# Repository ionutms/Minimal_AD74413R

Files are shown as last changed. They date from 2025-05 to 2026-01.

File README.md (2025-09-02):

# Minimal_AD74413R

## Overview

This repository contains a minimal KiCad design project for the Analog Devices AD74413R, a quad-channel, software-configurable input and output device. The project includes schematic designs and PCB layout files for implementing this versatile analog I/O device.

## Disclaimer

> [!NOTE]
> This project is provided "as is" and without any warranty, express or implied. For more details, please see the [LICENSE](LICENSE) file.

## About the AD74413R

The AD74413R from Analog Devices is a quad-channel, software-configurable input/output solution for building and process control applications. It integrates a 16-bit, sigma-delta (Σ-Δ) analog-to-digital converter (ADC) and four 13-bit digital-to-analog converters (DACs).

Key features include:

- **Software-Configurable Channels:** Each of the four channels can be independently configured as:
  - Analog Input (Voltage or Current)
  - Analog Output (Voltage or Current)
  - Digital Input
  - Resistance Temperature Detector (RTD) and Thermocouple measurements
- **Multiple Operating Modes:**
  - Voltage Output: 0 V to 10 V
  - Current Output: 0 mA to 24 mA
  - Voltage Input: ±10 V
  - Current Input: 0 mA to 24 mA (externally powered and loop-powered)
  - Digital Input: Logic and loop-powered
- **High Accuracy:** Includes a high-accuracy 2.5V internal reference.
- **Robustness and Diagnostics:** Features on-chip diagnostics like open-circuit and short-circuit detection.
- **HART Compatibility:** Compatible with HART (Highway Addressable Remote Transducer) protocol.
- **Communication:** Uses a Serial Peripheral Interface (SPI) for configuration and data transfer.
- **Operating Temperature Range:** -40°C to +105°C.

## Project Structure

```
minimal_ad74413r/
├── minimal_ad74413r.kicad_sch       # Main schematic file
├── minimal_ad74413r.kicad_pcb       # PCB layout file
├── minimal_ad74413r.kicad_pro       # Project configuration file
├── fp-lib-table                     # Footprint library table
├── sym-lib-table                    # Symbol library table
├── Front End Channel 1.kicad_sch    # Channel-specific schematic
├── project_jobs_set.kicad_jobset    # Project job settings
├── ibom.config.ini                  # Interactive BOM configuration
├── docs/                            # Documentation files
│   ├── pictures/                    # Images and photos
│   ├── schematics/                  # Schematic PDF exports
│   └── 3d_models/                   # 3D model files
└── KiCAD_Symbols_Generator/         # Submodule for symbol generation from CSV data
```

## Project Features

This design provides a minimal implementation of the AD74413R with the following features:

- **Power Supply:**
  - AVDD: +24V
  - AVSS: -24V
  - IOVDD: +3.3V
  - AVDD_REG and DVDD_REG: +1.8V (internally regulated)
- **Channel Configuration:**
  - Basic protection circuits for each of the four I/O channels.
  - Support for all operating modes of the AD74413R.
- **Bill of Materials (BOM):**
  - Interactive HTML BOM (`ibom.html`) for easy component identification and sourcing.
- **Libraries:**
  - Comprehensive symbol and footprint libraries integrated as a submodule.
- **3D Model:**
  - Includes a 3D model of the board for better visualization.

## Getting Started

### Prerequisites

- [KiCad EDA](https://www.kicad.org/) version 9.0 or later installed on your system
- Git (for cloning the repository and submodule management)

### Opening the Project

1. **Clone the repository** (including submodules):
   ```bash
   git clone --recursive https://github.com/ionutms/Minimal_AD74413R.git
   ```
   
   If you've already cloned the repository without submodules, initialize them with:
   ```bash
   git submodule init
   git submodule update
   ```

2. **Open the project in KiCad**:
   - Launch KiCad
   - Click "Open Existing Project"
   - Navigate to the cloned repository folder
   - Select the `minimal_ad74413r.kicad_pro` file

3. **Explore the design**:
   - Open the schematic editor to view the circuit design
   - Open the PCB editor to view the board layout
   - Review the symbol and footprint libraries used in the design

### Project Files

- **Main schematic**: `minimal_ad74413r.kicad_sch` - Contains the primary circuit design with the AD74413R and support components
- **Channel schematic**: `Front End Channel 1.kicad_sch` - Detailed implementation of one channel with protection and filtering
- **PCB layout**: `minimal_ad74413r.kicad_pcb` - Physical board design file with proper component placement
- **Project configuration**: `minimal_ad74413r.kicad_pro` - KiCad project settings

## Dependencies

This project has the following dependencies:

### 1. KiCAD Symbols Generator

This repository uses [KiCAD_Symbols_Generator](https://github.com/ionutms/KiCAD_Symbols_Generator) as a submodule for custom symbol generation.

To initialize the submodule after cloning this repository:

```bash
git submodule update --init --recursive
```

### 2. 3D Models

This project requires the [3D_Models_Vault](https://github.com/ionutms/3D_Models_Vault) repository for 3D models.

#### Setup for KiCAD 9:

1. Clone the 3D models repository:
   ```bash
   git clone https://github.com/ionutms/3D_Models_Vault.git
   ```

2. In KiCAD 9, add an environment variable:
   - Variable name: `KICAD9_3D_MODELS_VAULT`
   - Variable value: Full path to where you cloned the 3D_Models_Vault repository

## Usage

After setting up the dependencies, open the project in KiCad 9 to access all features including the 3D models.

## Symbol Generator Submodule

This project includes the KiCAD_Symbols_Generator as a submodule, which provides tools for generating KiCad symbols from CSV data files. For more information on using this tool, see the [KiCAD_Symbols_Generator documentation](minimal_ad74413r/KiCAD_Symbols_Generator/README.md).

## Documentation

The `docs` folder contains:
- Schematic PDF exports
- Images and photos of the design
- 3D model files (GLB and WRL formats)

## Visuals

The following images showcase the PCB design from different perspectives:

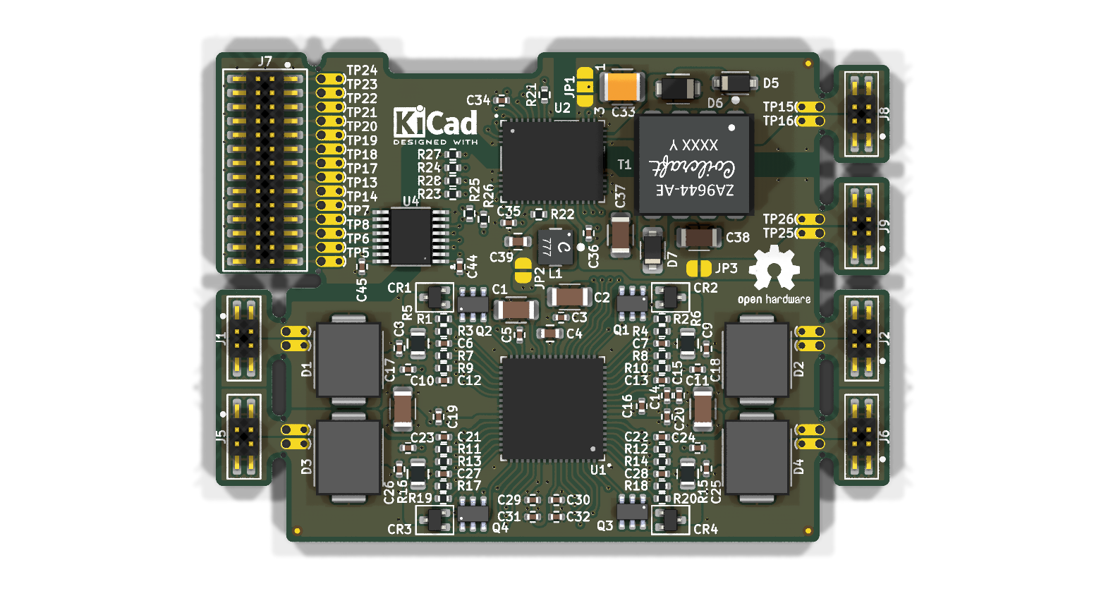
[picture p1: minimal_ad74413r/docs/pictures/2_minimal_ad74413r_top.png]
Top View

*Top View of the PCB*

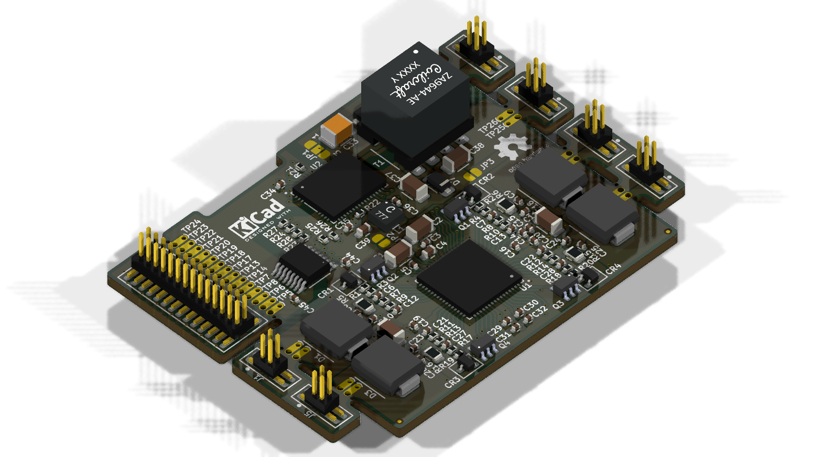
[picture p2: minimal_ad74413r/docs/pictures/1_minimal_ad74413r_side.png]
Side View

*Side View of the PCB*

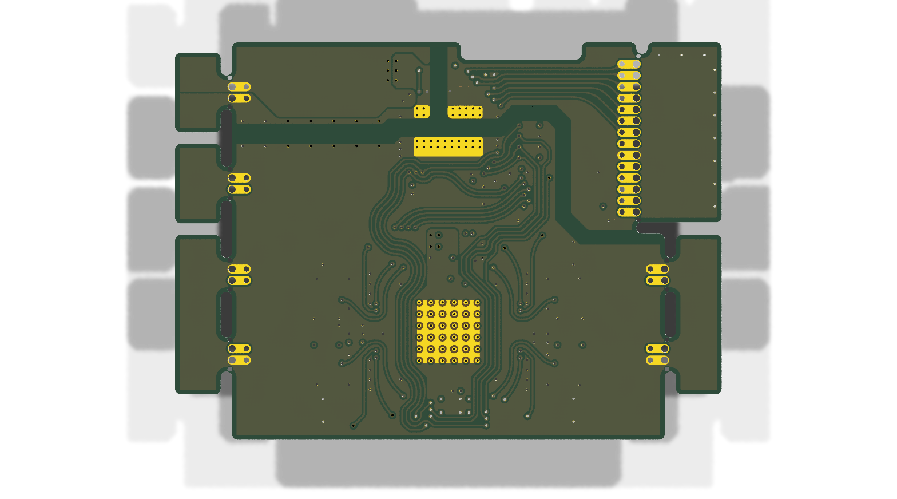
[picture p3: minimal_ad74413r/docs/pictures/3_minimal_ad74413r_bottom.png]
Bottom View

*Bottom View of the PCB*

## License

This project is licensed under the MIT License - see the [LICENSE](LICENSE) file for details.

## References

- [AD74413R Datasheet](https://www.analog.com/media/en/technical-documentation/data-sheets/ad74413r.pdf)
- [KiCad EDA](https://www.kicad.org/)

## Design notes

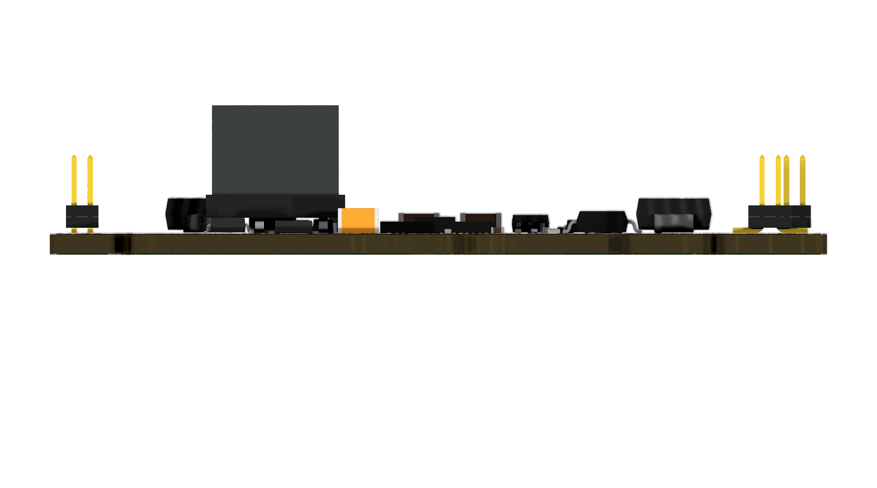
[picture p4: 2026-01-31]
minimal_ad74413r/docs/pictures/7_minimal_ad74413r_back.png

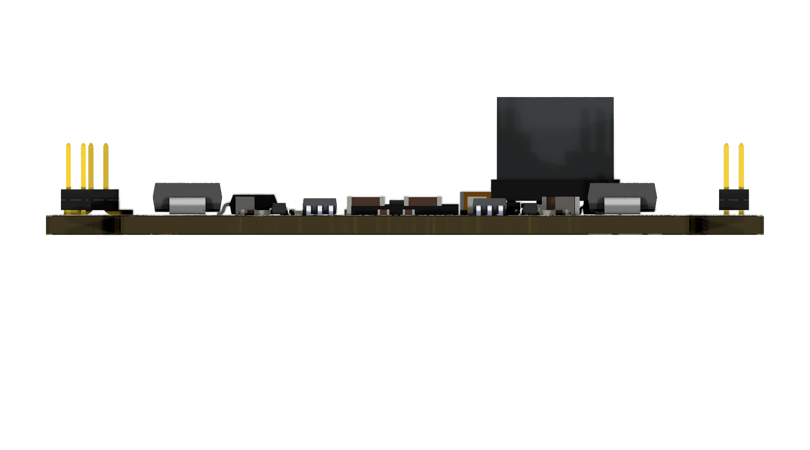
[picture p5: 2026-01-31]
minimal_ad74413r/docs/pictures/6_minimal_ad74413r_front.png

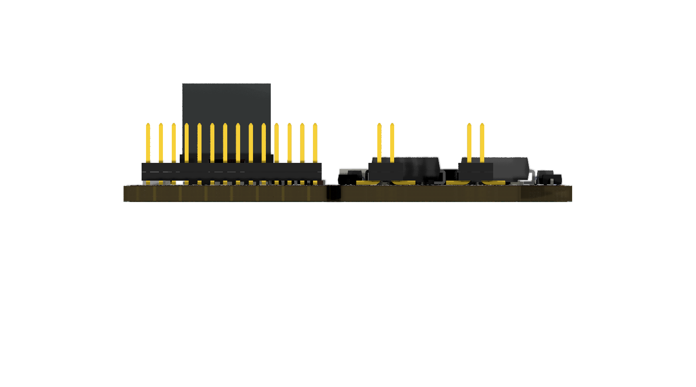
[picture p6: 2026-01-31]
minimal_ad74413r/docs/pictures/4_minimal_ad74413r_left.png

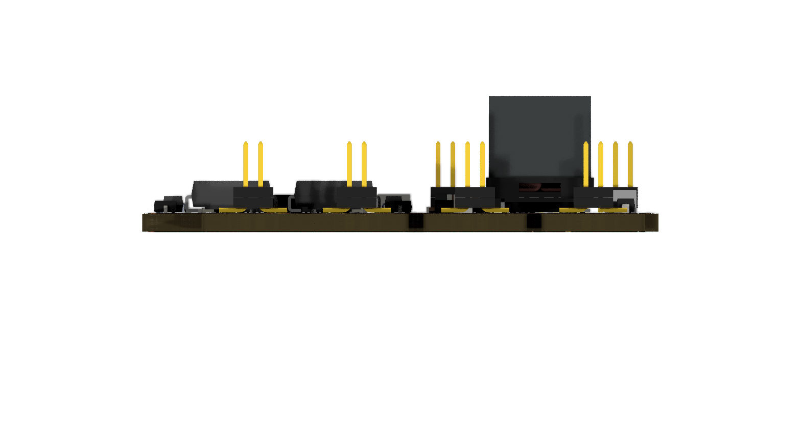
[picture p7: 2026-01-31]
minimal_ad74413r/docs/pictures/5_minimal_ad74413r_right.png

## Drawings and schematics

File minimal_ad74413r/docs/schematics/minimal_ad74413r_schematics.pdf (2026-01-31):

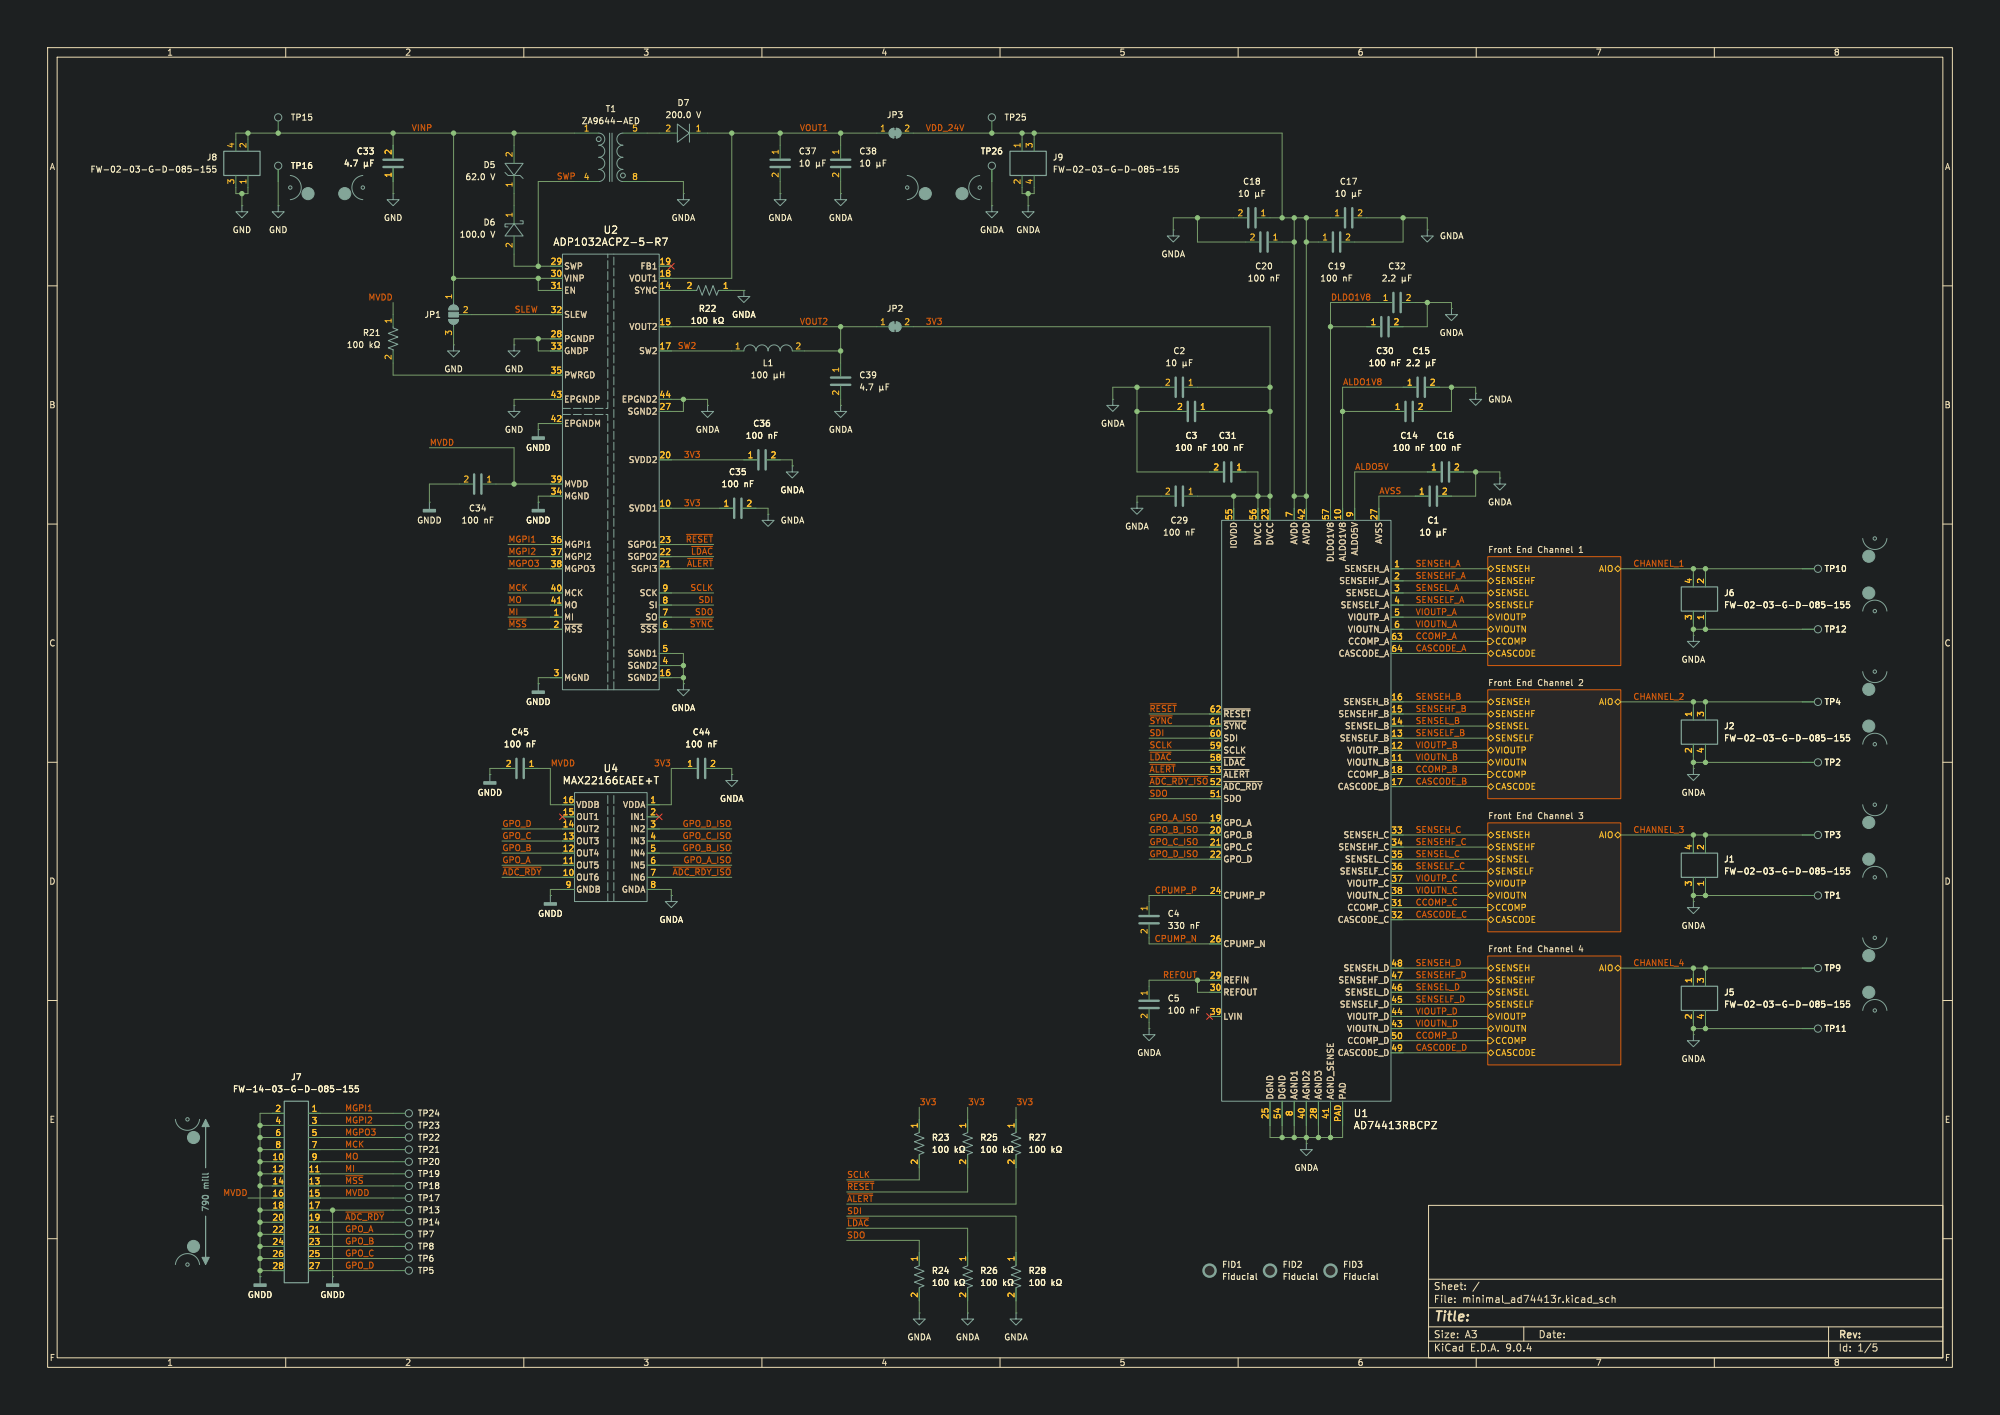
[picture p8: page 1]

SWP 29 VINP 30 EN 31 SLEW 32 PGNDP 28 GNDP 33 PWRGD 35 EPGNDP 43 EPGNDM 42 MVDD 39 MGND 34 MGPI1 36 MGPI2 37 MGPO3 38 MCK 40 MO 41 MI 1 MGND 3

SWP

9 AVSS27 SENSEH_A 1 SENSEHF_A 2 SENSEL_A 3 SENSELF_A 4 VIOUTP_A 5 VIOUTN_A 6 CCOMP_A 63 CASCODE_A64 SENSEH_B 16 SENSEHF_B 15 SENSEL_B 14 SENSELF_B 13 VIOUTP_B 12 VIOUTN_B 11 CCOMP_B 18 CASCODE_B 17 SENSEH_C 33 SENSEHF_C 34 SENSEL_C 35 SENSELF_C 36 VIOUTP_C 37 VIOUTN_C 38 CCOMP_C 31 CASCODE_C32 SENSEH_D 48 SENSEHF_D 47 SENSEL_D 46 SENSELF_D 45 VIOUTP_D 44 VIOUTN_D 43 CCOMP_D 50 CASCODE_D49 ~{RESET} 62 ~{SYNC} 61 ~{LDAC} 58 ~{ALERT} 53 ~{ADC_RDY} 52 DGND 25 DGND 54 AGND1

IN6 7 GNDA 8 VDDB 16 OUT1 15 OUT2 14 OUT3 13 OUT4 12 OUT5 11 OUT6 10 GNDB 9 GNDD

Id: 1/5 Title: File: minimal_ad74413r.kicad_sch Sheet: /

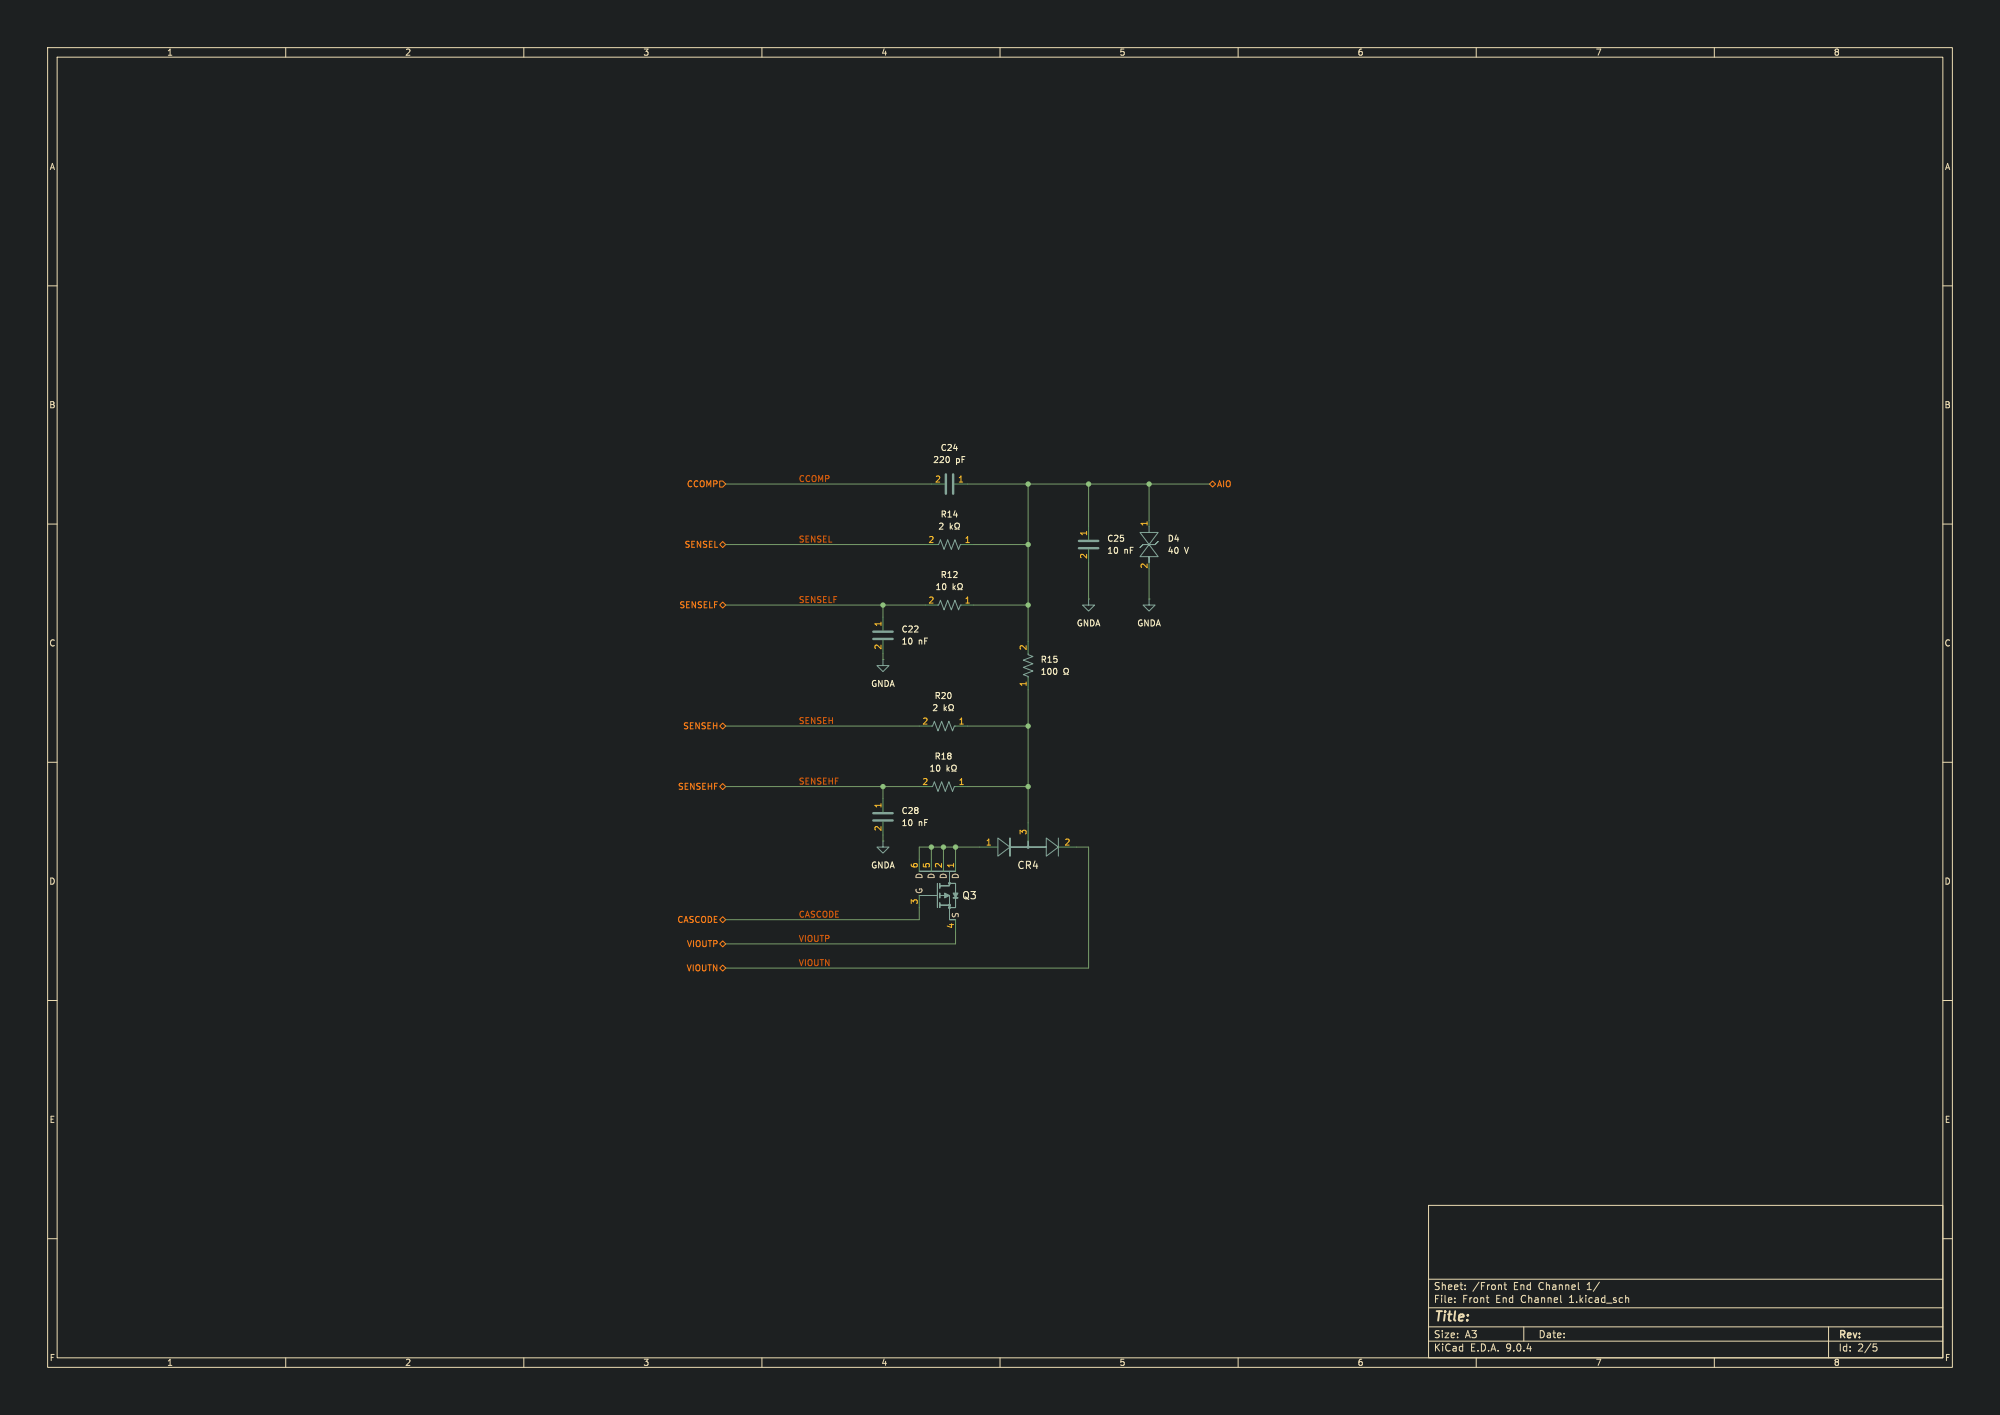
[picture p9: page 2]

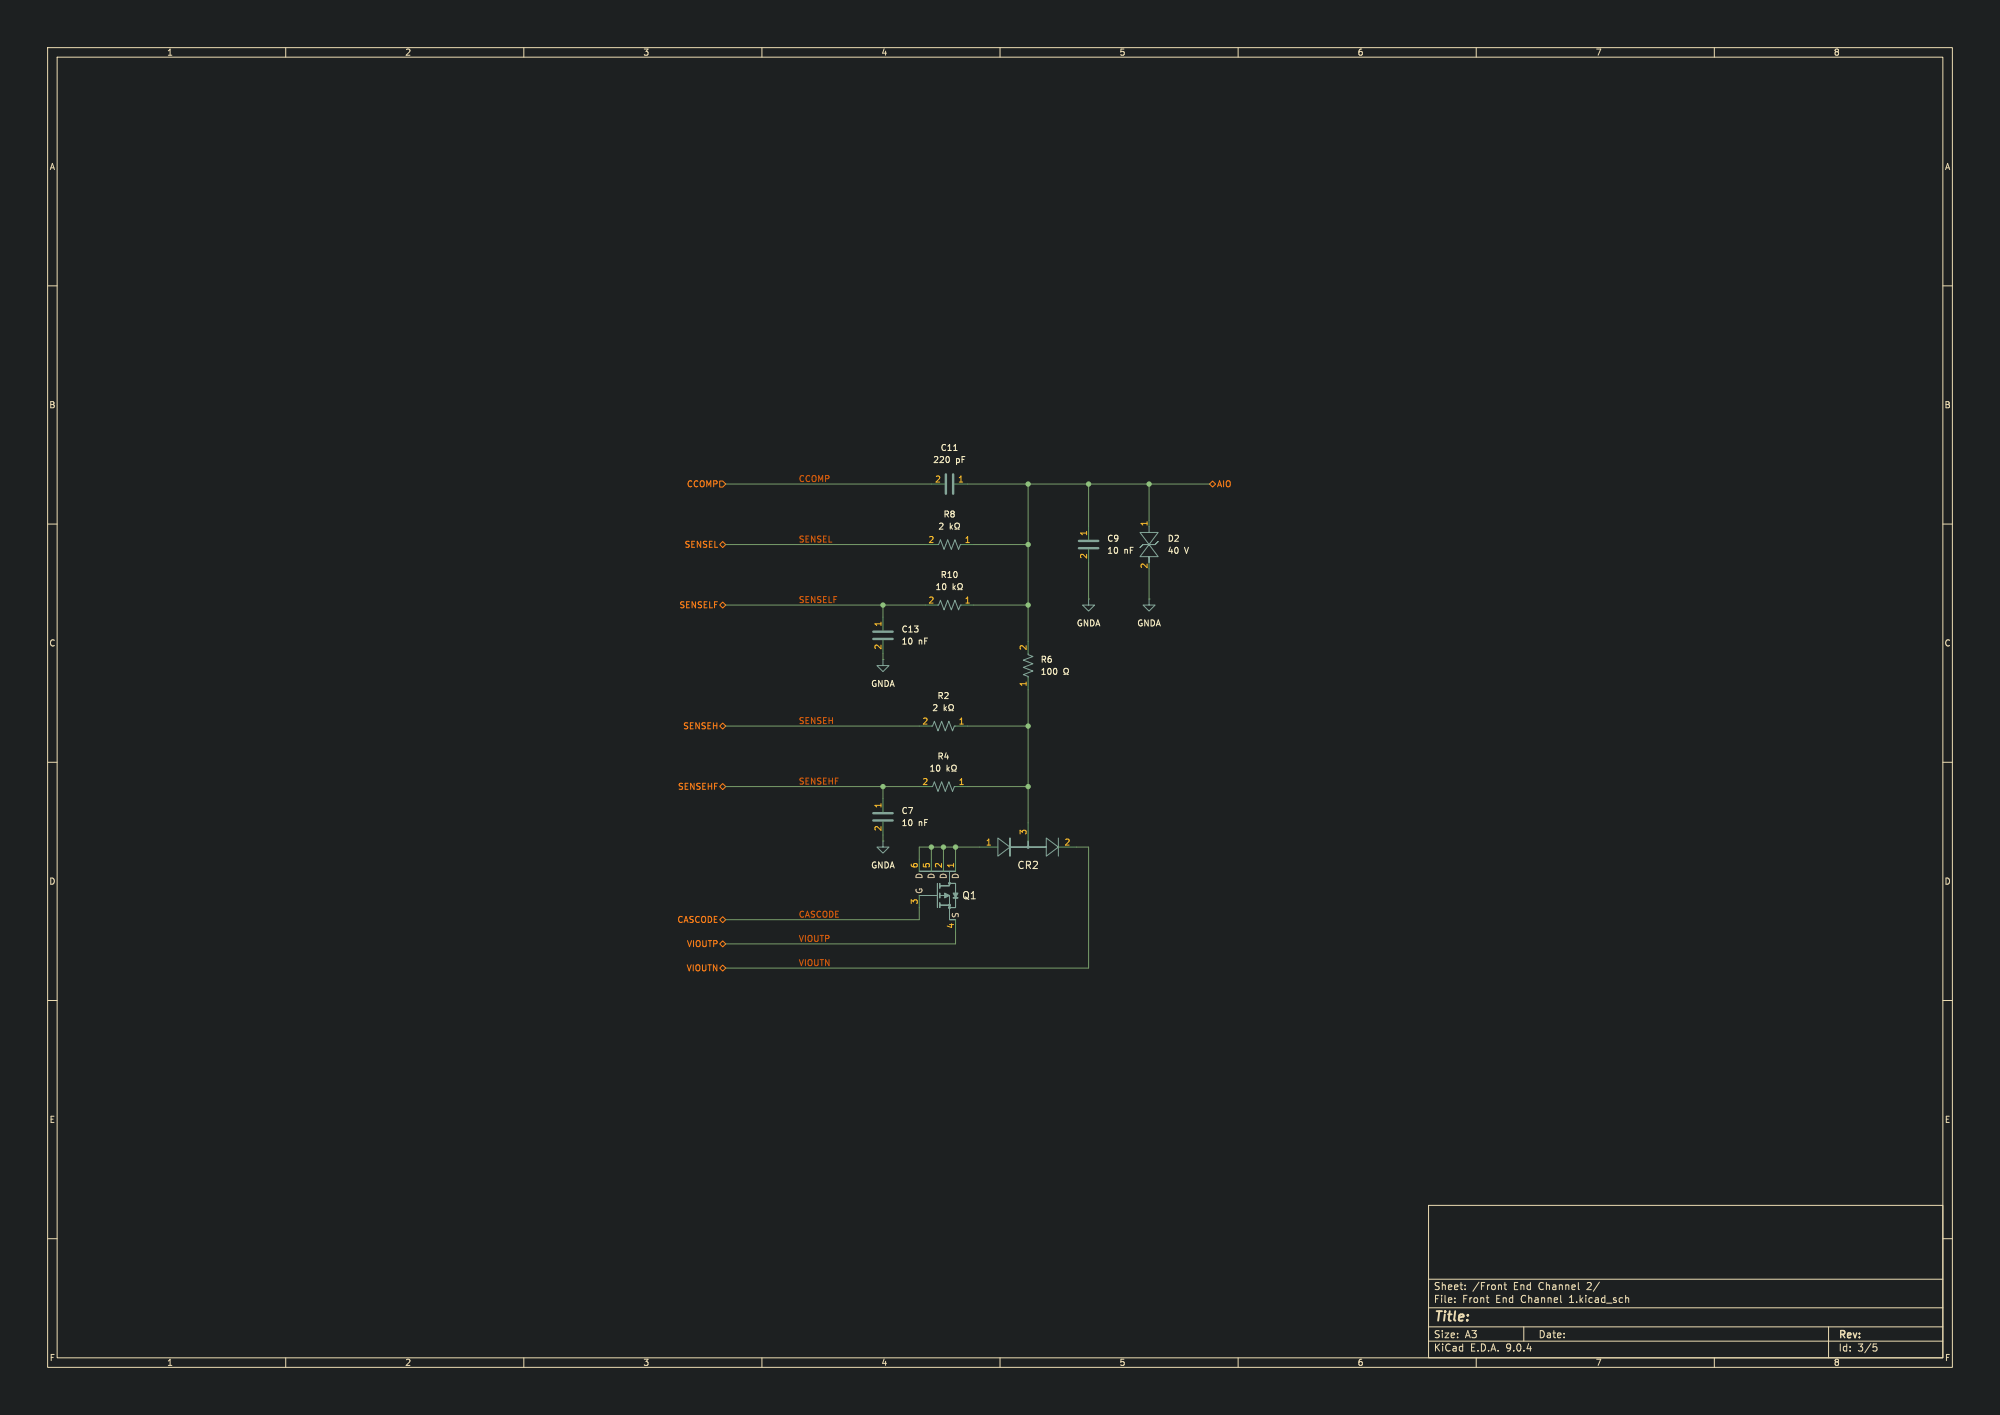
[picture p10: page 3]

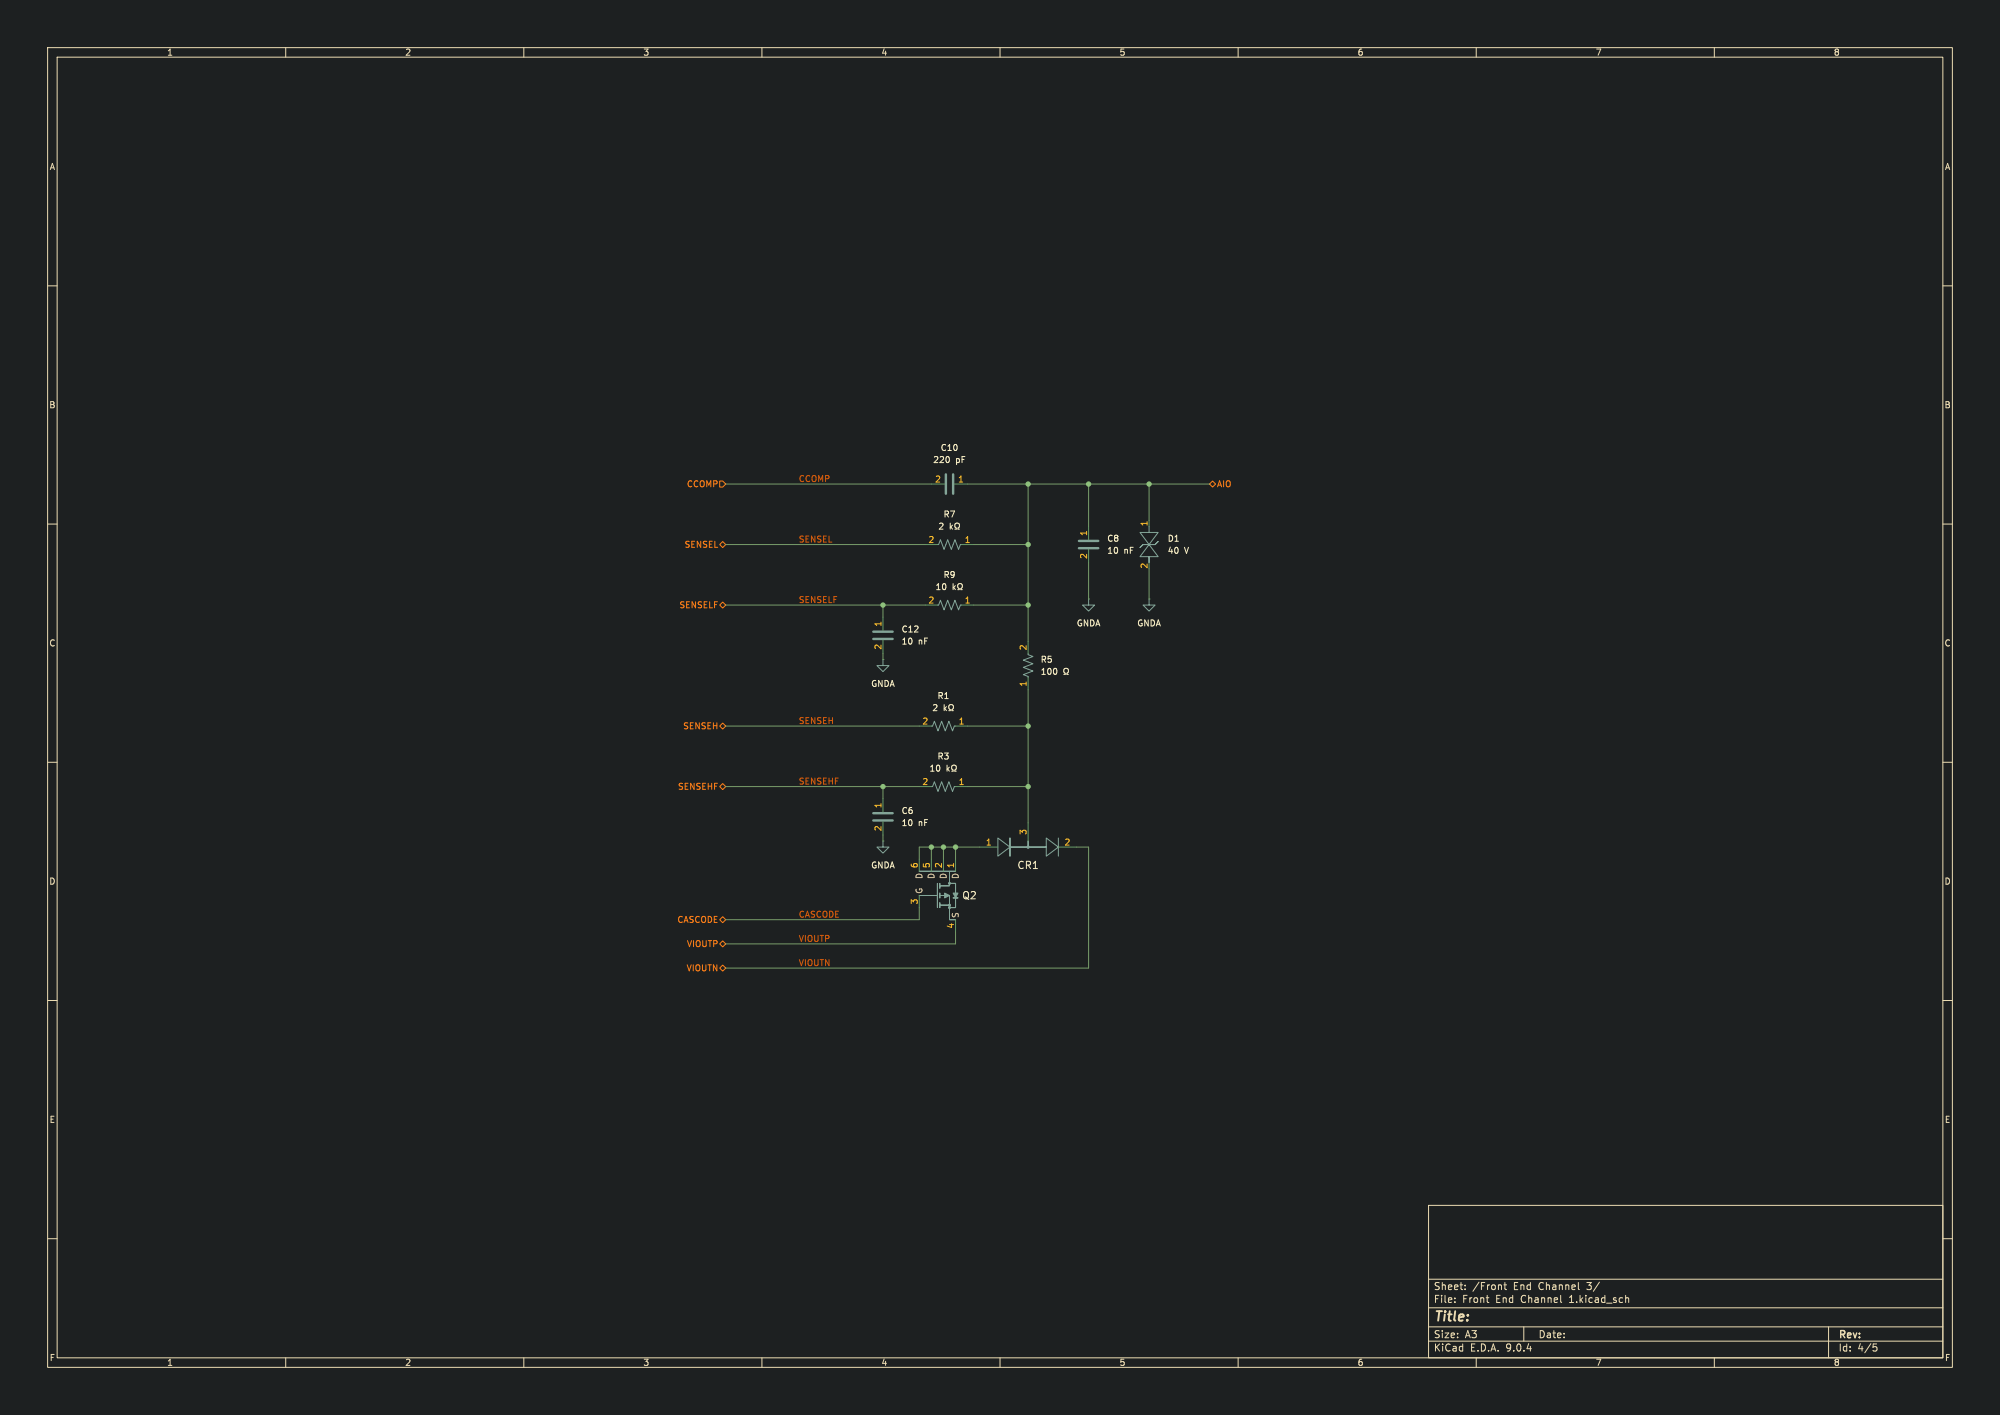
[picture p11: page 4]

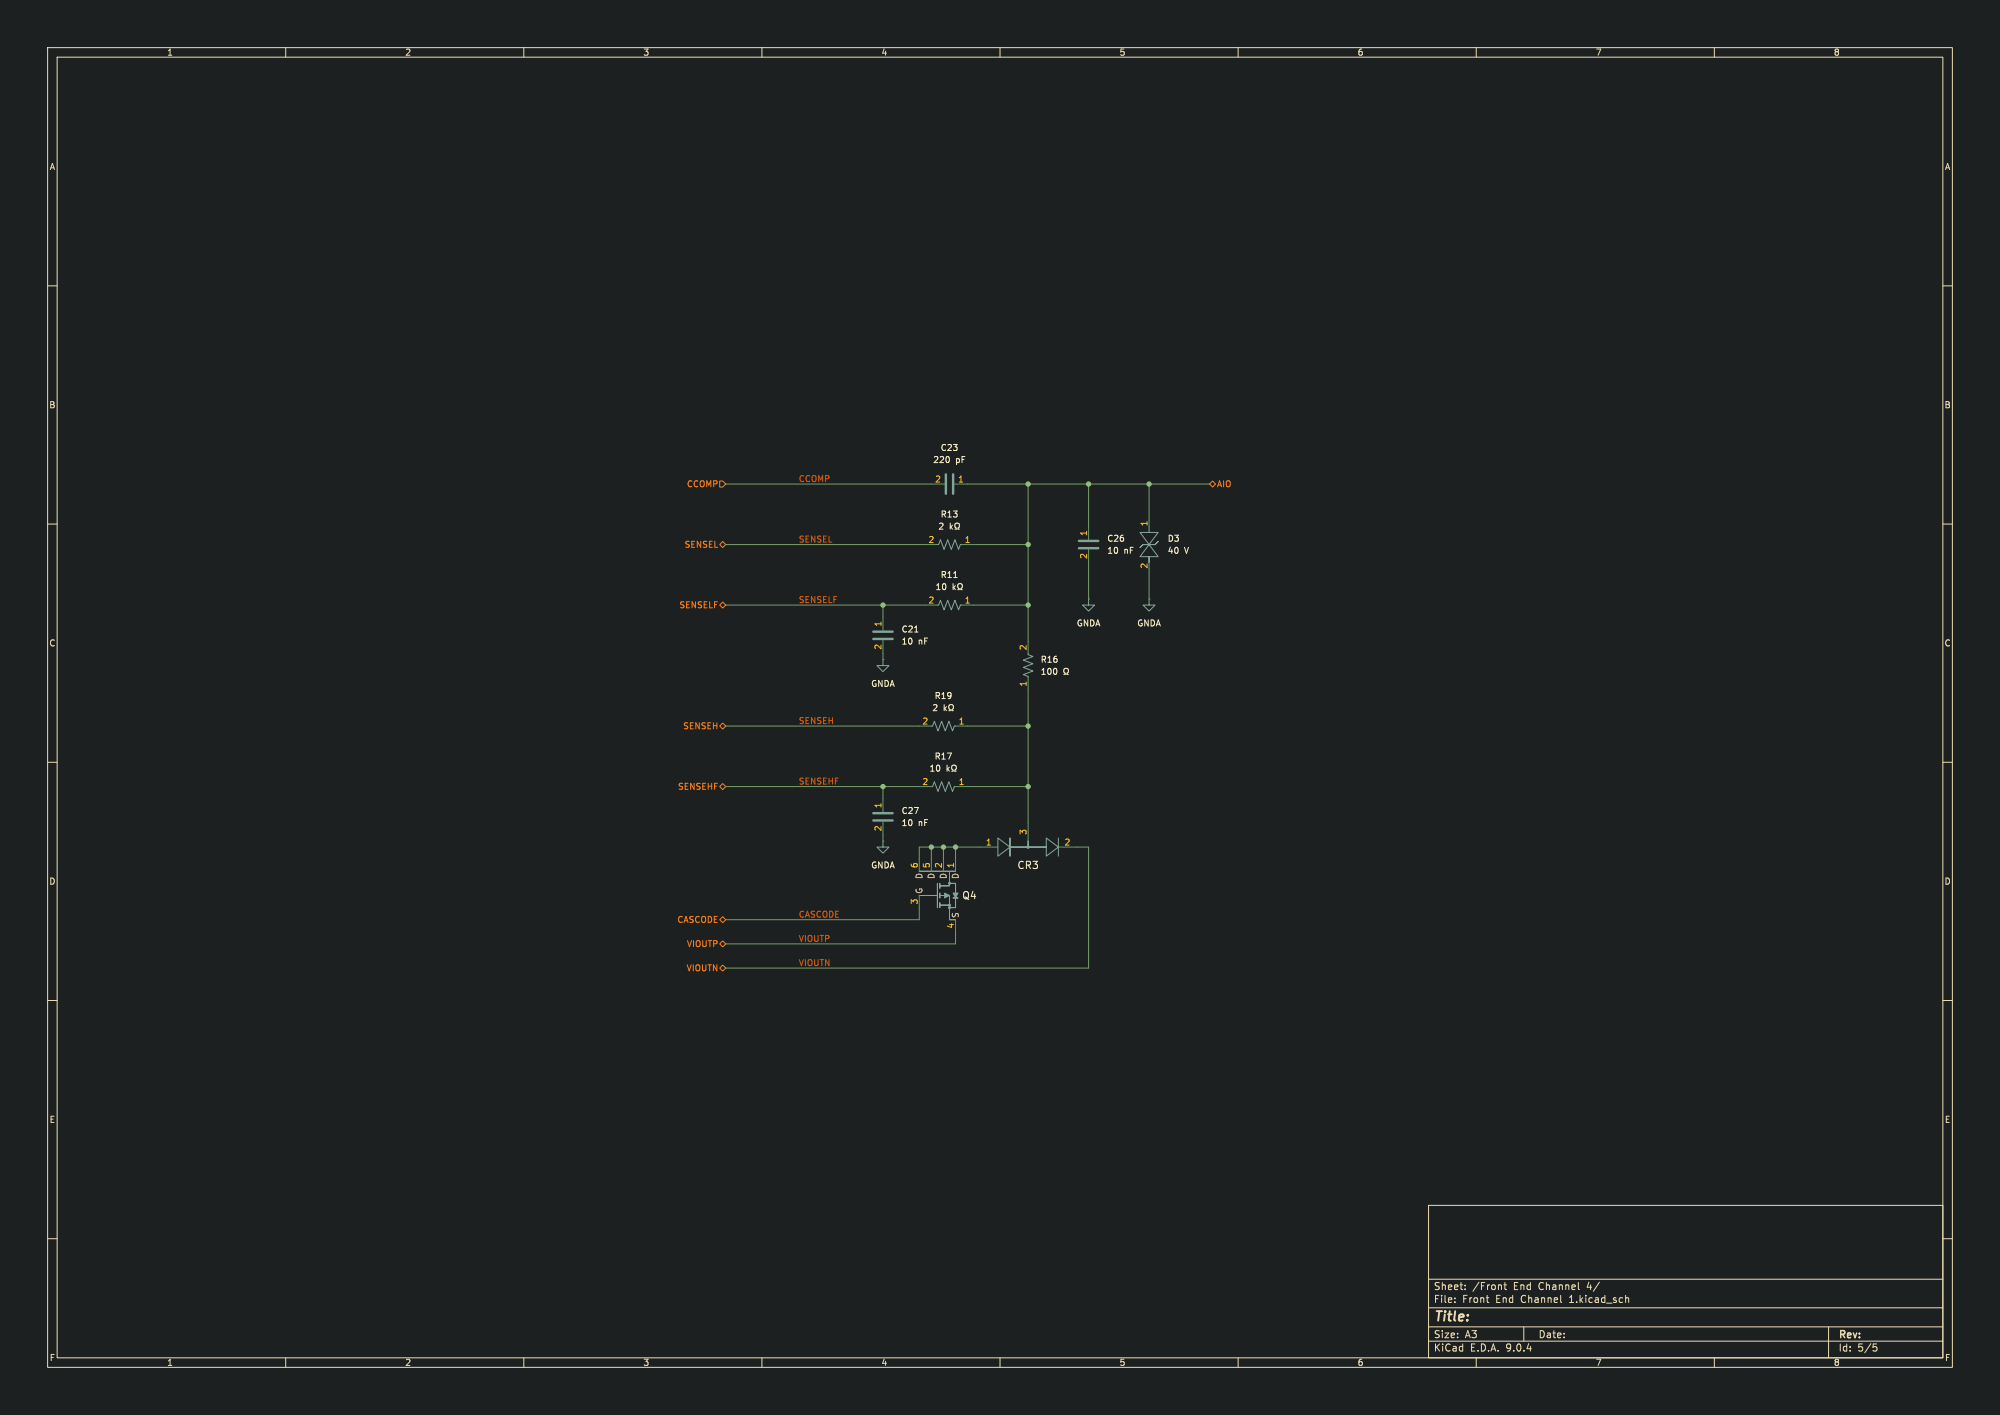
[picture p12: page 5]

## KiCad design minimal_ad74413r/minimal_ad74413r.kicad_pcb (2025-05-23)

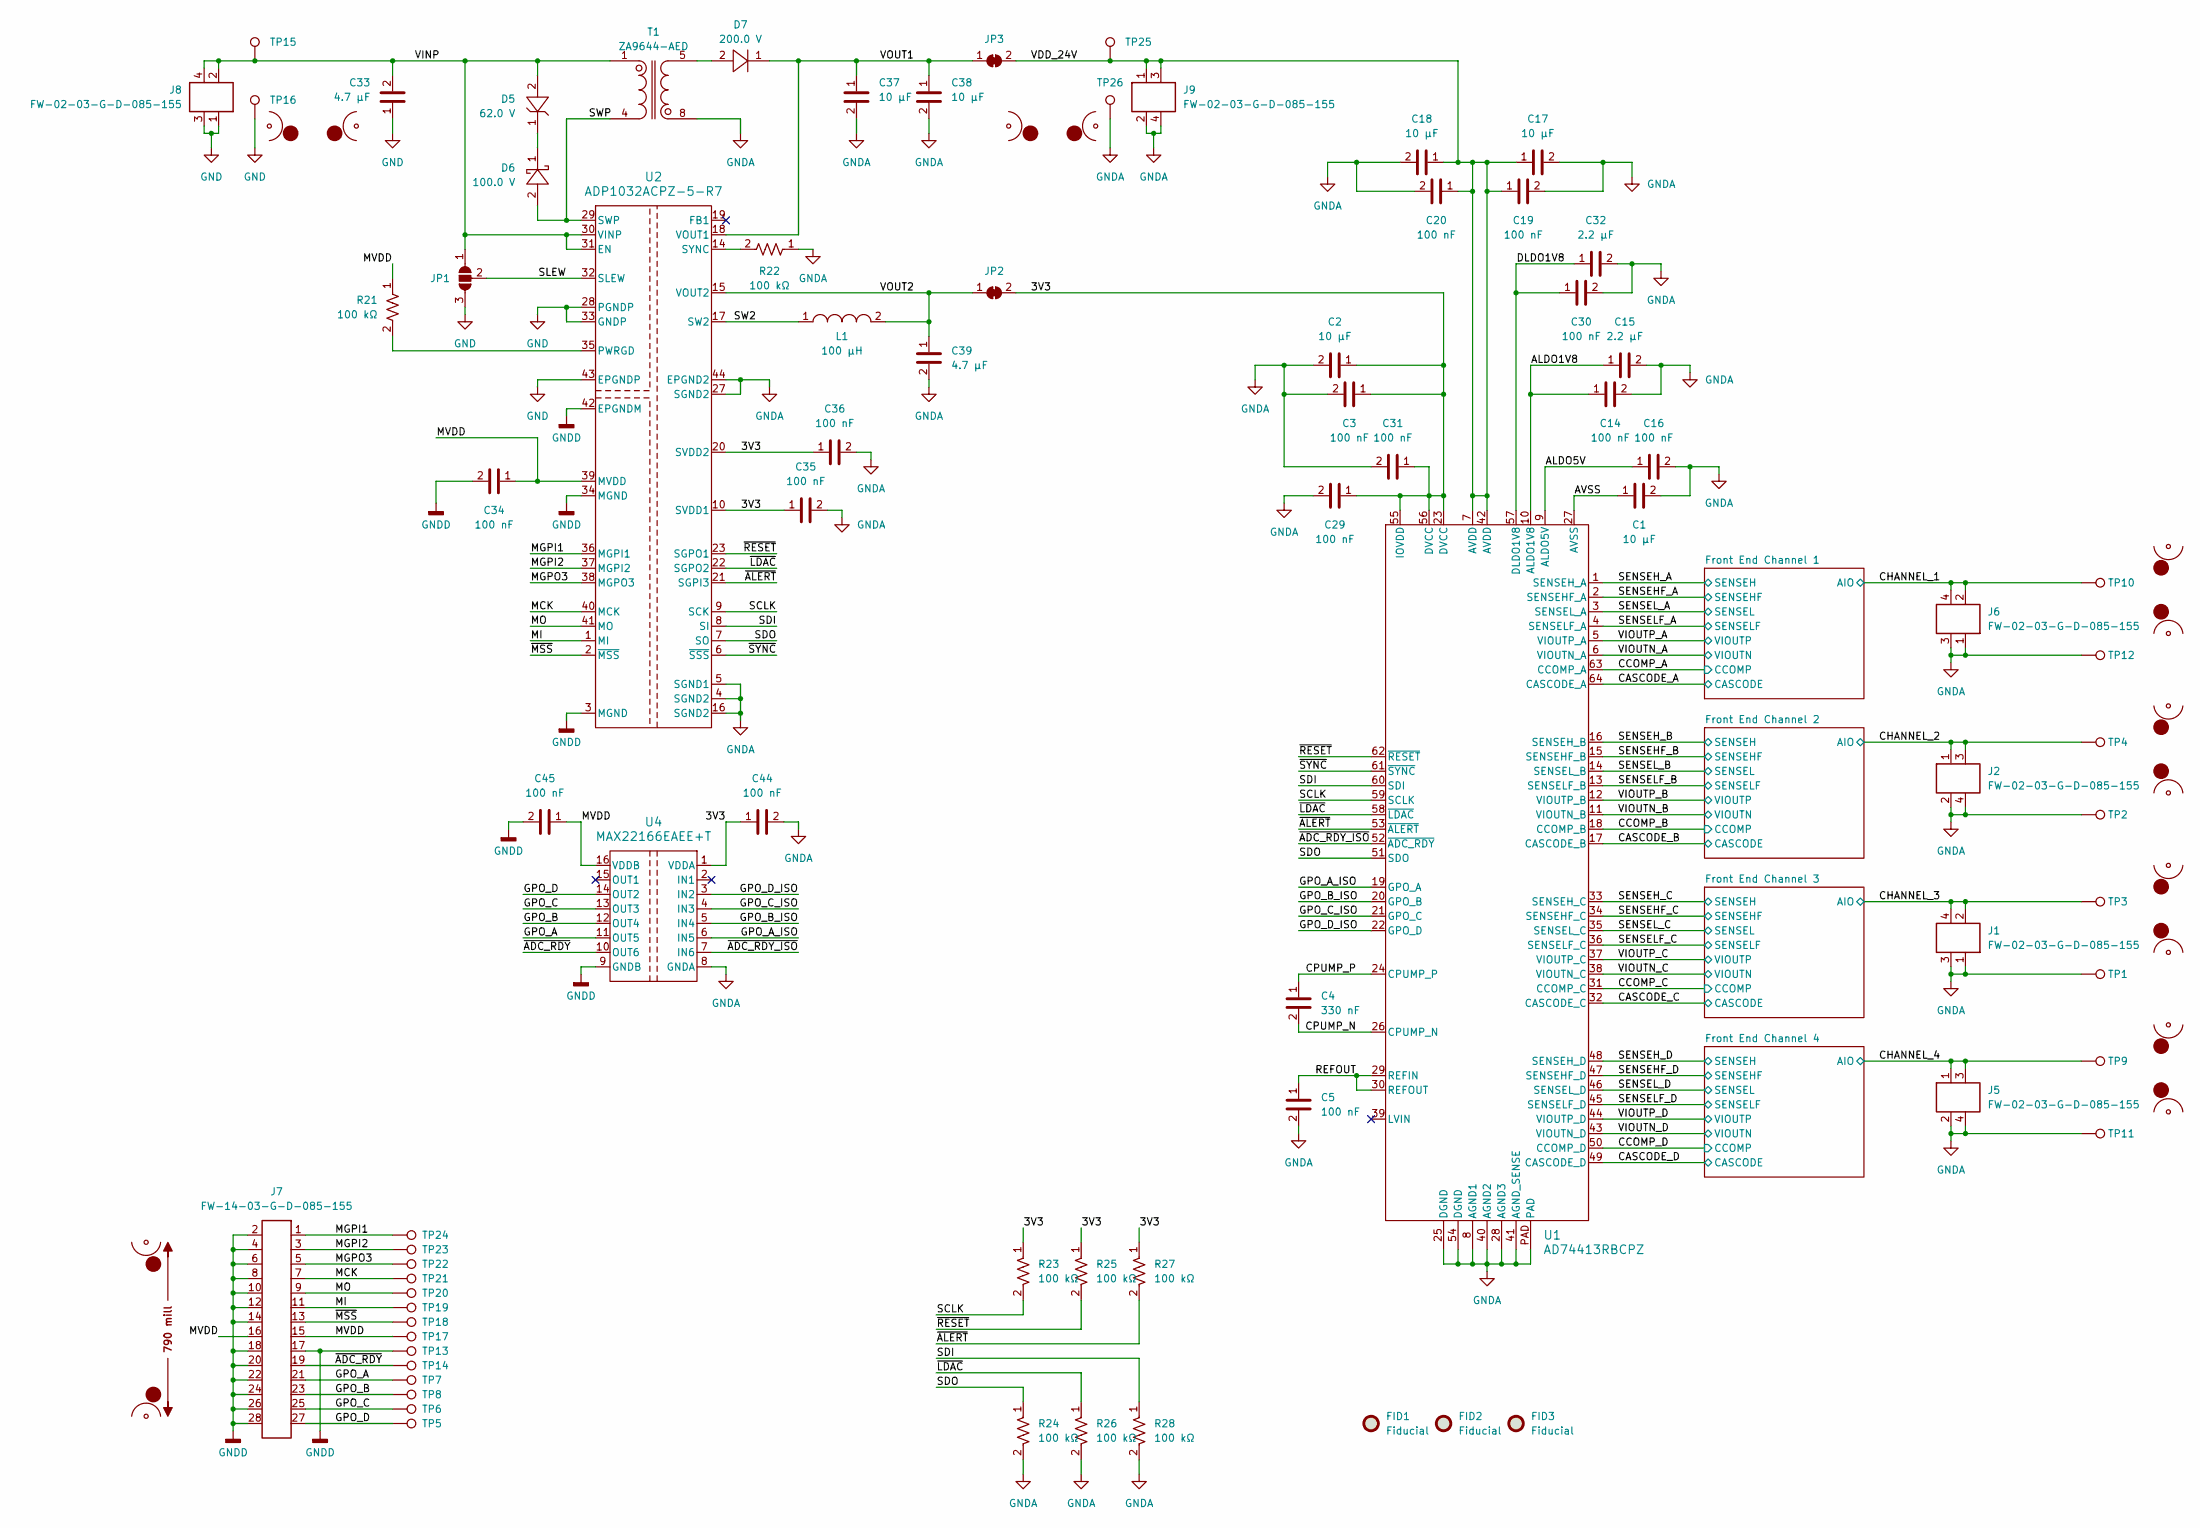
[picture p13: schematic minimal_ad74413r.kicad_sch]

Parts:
C1, C2, C17, C18, C37, C38: 10 µF; C_1206_3216Metric; Voltage Rating DC 50 VDC; Tolerance 10%; MPN CL31B106KBHNNN#
C3, C5, C14, C16, C19, C20, C29, C30, C31, C34, C35, C36, C44, C45: 100 nF; C_0402_1005Metric; Voltage Rating DC 50 VDC; Tolerance 10%; MPN GCM155R71H104KE02D
C4: 330 nF; C_0603_1608Metric; Voltage Rating DC 10 VDC; Tolerance 10%; MPN GRM188R71A334KA61D
C15, C32: 2.2 µF; C_0402_1005Metric; Voltage Rating DC 10 VDC; Tolerance 10%; MPN GRM155Z71A225KE44D
C33: 4.7 µF; C_1210_200_3225Metric; Tolerance 10%; Voltage Rating 100V; MPN GCM32DC72A475KE02K
C39: 4.7 µF; C_0603_1608Metric; Voltage Rating DC 10 VDC; Tolerance 10%; MPN C1608X7S1A475K080AC
D5: 62.0 V; SOD_123; MPN MMSZ5265BT1G
D6: 100.0 V; PowerDI_123; MPN DFLS1200-7
D7: 200.0 V; SOD_123F; MPN US1DWF
FID1, FID2, FID3: Fiducial; Fiducial_0.5mm_Mask1mm
J1, J2, J5, J6, J8, J9: FW-02-03-G-D-085-155; Current Rating (A) 5.2; Voltage Rating (V) 300; MPN FW-02-03-G-D-085-155
J7: FW-14-03-G-D-085-155; Current Rating (A) 5.2; Voltage Rating (V) 300; MPN FW-14-03-G-D-085-155
JP1: SolderJumper_3_Open; SolderJumper-3_P1.3mm_Open_RoundedPad1.0x1.5mm_NumberLabels
JP2, JP3: SolderJumper_2_Bridged; SolderJumper-2_P1.3mm_Bridged_RoundedPad1.0x1.5mm
L1: 100 µH; XFL3012; Tolerance ±20%; MPN XFL3012-104ME
MB1, MB2, MB5, MB6, MB8, MB9: mouse-bite-midle-50mil-200mil
MB7: mouse-bite-midle-50mil-200mil; mouse-bite-50mil-790mil
R21, R22, R23, R24, R25, R26, R27, R28: 100 kΩ; R_0402_1005Metric; Voltage Rating 50V; Tolerance 5%; MPN ERJ-2GEJ104X
T1: ZA9644-AED; ZA9644; Tolerance ±10%; MPN ZA9644-AED
TP1, TP2, TP3, TP4, TP5, TP6, TP7, TP8, TP9, TP10, TP11, TP12, TP13, TP14, TP15, TP16, TP17, TP18, TP19, TP20, TP21, TP22, TP23, TP24, TP25, TP26: TestPoint; TestPoint_THTPad_Castelated
U1: AD74413RBCPZ; CP-64-15_ADI; MPN AD74413RBCPZ
U2: ADP1032ACPZ-5-R7; CP-41-1_ADI; MPN ADP1032ACPZ-5-R7
U4: MAX22166EAEE+T; 21-0055_E16MS&plus_2_MXM_ADI; MPN MAX22166EAEE+T

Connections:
/3V3: C2.1, C3.1, C29.1, C31.1, C35.1, C36.1, C44.1, JP2.2, R23.1, R25.1, R27.1, U1.23 (DVCC), U1.55 (IOVDD), U1.56 (DVCC), U2.10 (SVDD1), U2.20 (SVDD2), U4.1 (VDDA)
/ALDO1V8: C14.1, C15.1, U1.10 (ALDO1V8)
/ALDO5V: C16.1, U1.9 (ALDO5V)
/AVSS: C1.1, U1.27 (AVSS)
/CASCODE_A: U1.64 (CASCODE_A); also elsewhere on the board
/CASCODE_B: U1.17 (CASCODE_B); also elsewhere on the board
/CASCODE_C: U1.32 (CASCODE_C); also elsewhere on the board
/CASCODE_D: U1.49 (CASCODE_D); also elsewhere on the board
/CCOMP_A: U1.63 (CCOMP_A); also elsewhere on the board
/CCOMP_B: U1.18 (CCOMP_B); also elsewhere on the board
/CCOMP_C: U1.31 (CCOMP_C); also elsewhere on the board
/CCOMP_D: U1.50 (CCOMP_D); also elsewhere on the board
/CHANNEL_1: J6.2, J6.4, TP10.1; also elsewhere on the board
/CHANNEL_2: J2.1, J2.3, TP4.1; also elsewhere on the board
/CHANNEL_3: J1.2, J1.4, TP3.1; also elsewhere on the board
/CHANNEL_4: J5.1, J5.3, TP9.1; also elsewhere on the board
/CPUMP_N: C4.2, U1.26 (CPUMP_N)
/CPUMP_P: C4.1, U1.24 (CPUMP_P)
/DLDO1V8: C30.1, C32.1, U1.57 (DLDO1V8)
/GPO_A: J7.21, TP7.1, U4.11 (OUT5)
/GPO_A_ISO: U1.19 (GPO_A), U4.6 (IN5)
/GPO_B: J7.23, TP8.1, U4.12 (OUT4)
/GPO_B_ISO: U1.20 (GPO_B), U4.5 (IN4)
/GPO_C: J7.25, TP6.1, U4.13 (OUT3)
/GPO_C_ISO: U1.21 (GPO_C), U4.4 (IN3)
/GPO_D: J7.27, TP5.1, U4.14 (OUT2)
/GPO_D_ISO: U1.22 (GPO_D), U4.3 (IN2)
/MCK: J7.7, TP21.1, U2.40 (MCK)
/MGPI1: J7.1, TP24.1, U2.36 (MGPI1)
/MGPI2: J7.3, TP23.1, U2.37 (MGPI2)
/MGPO3: J7.5, TP22.1, U2.38 (MGPO3)
/MI: J7.11, TP19.1, U2.1 (MI)
/MO: J7.9, TP20.1, U2.41 (MO)
/MVDD: C34.1, C45.1, J7.15, J7.16, R21.1, TP17.1, U2.39 (MVDD), U4.16 (VDDB)
/REFOUT: C5.1, U1.29 (REFIN), U1.30 (REFOUT)
/SCLK: R23.2, U1.59 (SCLK), U2.9 (SCK)
/SDI: R28.1, U1.60 (SDI), U2.8 (SI)
/SDO: R24.1, U1.51 (SDO), U2.7 (SO)
/SENSEHF_A: U1.2 (SENSEHF_A); also elsewhere on the board
/SENSEHF_B: U1.15 (SENSEHF_B); also elsewhere on the board
/SENSEHF_C: U1.34 (SENSEHF_C); also elsewhere on the board
/SENSEHF_D: U1.47 (SENSEHF_D); also elsewhere on the board
/SENSEH_A: U1.1 (SENSEH_A); also elsewhere on the board
/SENSEH_B: U1.16 (SENSEH_B); also elsewhere on the board
/SENSEH_C: U1.33 (SENSEH_C); also elsewhere on the board
/SENSEH_D: U1.48 (SENSEH_D); also elsewhere on the board
/SENSELF_A: U1.4 (SENSELF_A); also elsewhere on the board
/SENSELF_B: U1.13 (SENSELF_B); also elsewhere on the board
/SENSELF_C: U1.36 (SENSELF_C); also elsewhere on the board
/SENSELF_D: U1.45 (SENSELF_D); also elsewhere on the board
/SENSEL_A: U1.3 (SENSEL_A); also elsewhere on the board
/SENSEL_B: U1.14 (SENSEL_B); also elsewhere on the board
/SENSEL_C: U1.35 (SENSEL_C); also elsewhere on the board
/SENSEL_D: U1.46 (SENSEL_D); also elsewhere on the board
/SLEW: JP1.2 (C), U2.32 (SLEW)
/SW2: L1.1, U2.17 (SW2)
/SWP: D6.2, T1.4, U2.29 (SWP)
/VDD_24V: C17.1, C18.1, C19.1, C20.1, J9.1, J9.3, JP3.2, TP25.1, U1.7 (AVDD), U1.42 (AVDD)
/VINP: C33.2, D5.2, J8.2, J8.4, JP1.1 (A), T1.1, TP15.1, U2.30 (VINP), U2.31 (EN)
/VIOUTN_A: U1.6 (VIOUTN_A); also elsewhere on the board
/VIOUTN_B: U1.11 (VIOUTN_B); also elsewhere on the board
/VIOUTN_C: U1.38 (VIOUTN_C); also elsewhere on the board
/VIOUTN_D: U1.43 (VIOUTN_D); also elsewhere on the board
/VIOUTP_A: U1.5 (VIOUTP_A); also elsewhere on the board
/VIOUTP_B: U1.12 (VIOUTP_B); also elsewhere on the board
/VIOUTP_C: U1.37 (VIOUTP_C); also elsewhere on the board
/VIOUTP_D: U1.44 (VIOUTP_D); also elsewhere on the board
/VOUT1: C37.1, C38.1, D7.1, JP3.1, U2.18 (VOUT1)
/VOUT2: C39.1, JP2.1, L1.2, U2.15 (VOUT2)
/~ADC_RDY_ISO: U1.52 (~ADC_RDY), U4.7 (IN6)
/~ADC_RDY: J7.19, TP14.1, U4.10 (OUT6)
/~ALERT: R27.2, U1.53 (~ALERT), U2.21 (SGPI3)
/~LDAC: R26.1, U1.58 (~LDAC), U2.22 (SGPO2)
/~MSS: J7.13, TP18.1, U2.2 (~MSS)
/~RESET: R25.2, U1.62 (~RESET), U2.23 (SGPO1)
/~SYNC: U1.61 (~SYNC), U2.6 (~SSS)
GND: C33.1, J8.1, J8.3, JP1.3 (B), TP16.1, U2.28 (PGNDP), U2.33 (GNDP), U2.43 (EPGNDP)
GNDA: C1.2, C2.2, C3.2, C5.2, C14.2, C15.2, C16.2, C17.2, C18.2, C19.2, C20.2, C29.2, C30.2, C31.2, C32.2, C35.2, C36.2, C37.2, C38.2, C39.2, C44.2, J1.1, J1.3, J2.2, J2.4, J5.2, J5.4, J6.1, J6.3, J9.2, J9.4, R22.1, R24.2, R26.2, R28.2, T1.8, TP1.1, TP2.1, TP11.1, TP12.1, TP26.1, U1.8 (AGND1), U1.25 (DGND), U1.28 (AGND3), U1.40 (AGND2), U1.41 (AGND_SENSE), U1.54 (DGND), U1.PAD, U2.4 (SGND2), U2.5 (SGND1), U2.16 (SGND2), U2.27 (SGND2), U2.44 (EPGND2), U4.8 (GNDA); also elsewhere on the board
GNDD: C34.2, C45.2, J7.2, J7.4, J7.6, J7.8, J7.10, J7.12, J7.14, J7.17, J7.18, J7.20, J7.22, J7.24, J7.26, J7.28, TP13.1, U2.3 (MGND), U2.34 (MGND), U2.42 (EPGNDM), U4.9 (GNDB)
unnamed: D5.1, D6.1
unnamed: D7.2, T1.5
unnamed: R21.2, U2.35 (PWRGD)
unnamed: R22.2, U2.14 (SYNC)

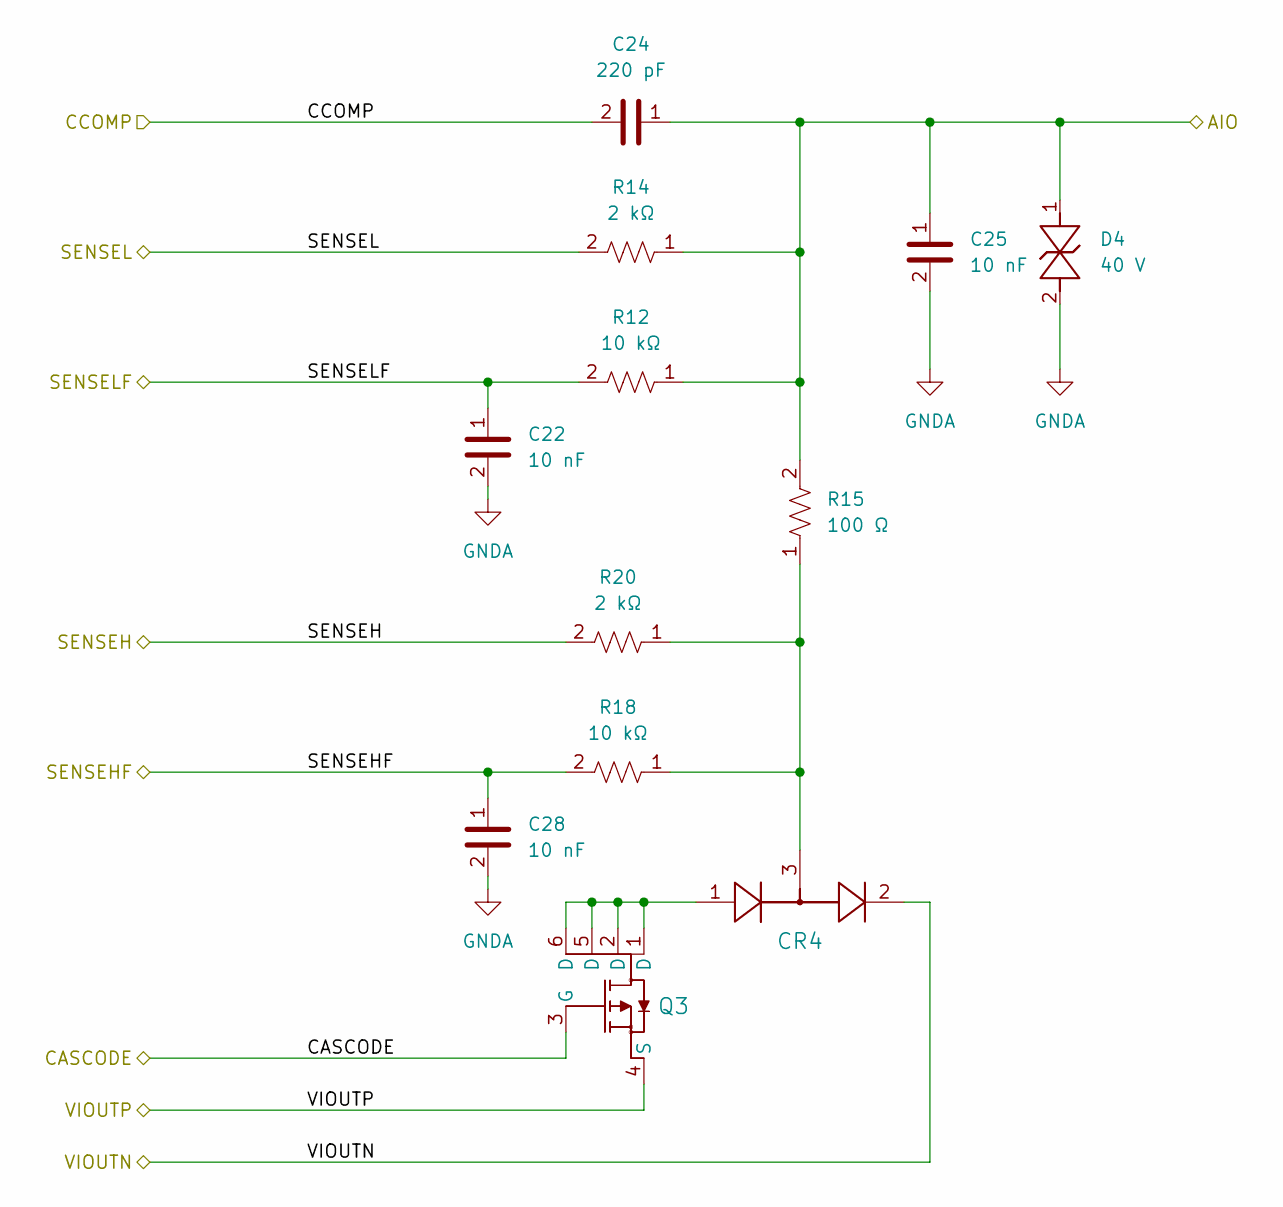
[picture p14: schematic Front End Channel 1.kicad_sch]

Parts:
C22, C25, C28: 10 nF; C_0402_1005Metric; Voltage Rating DC 100 VDC; Tolerance 10%; MPN C1005X7S2A103K050BB
C24: 220 pF; C_0402_1005Metric; Voltage Rating DC 100 VDC; Tolerance 5%; MPN CGA2B2NP02A221J050BA
CR4: 100 V; SC_70; MPN SBAV99WT1G
D4: 40 V; DO-214AB-2; MPN SMCJ40A/CA
Q3: -60 V; SOT-26; MPN ZXMP6A17E6TA
R12, R18: 10 kΩ; R_0402_1005Metric; Voltage Rating 50V; Tolerance 1%; MPN ERJ-2RKF1002X
R14: 2 kΩ; R_0402_1005Metric; Voltage Rating 50V; Tolerance 1%; MPN ERJ-2RKF2001X
R15: 100 Ω; R_0805_2012Metric; Voltage Rating 150V; Tolerance 0.1%; MPN RT0805BRB07100RL
R20: 2 kΩ; R_0402_1005Metric; Voltage Rating 50V; Tolerance 0.1%; MPN ERA-2AEB202X

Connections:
/CASCODE_A: Q3.3 (G); also elsewhere on the board
/CCOMP_A: C24.2; also elsewhere on the board
/CHANNEL_1: C24.1, C25.1, D4.1, R12.1, R14.1, R15.2; also elsewhere on the board
/SENSEHF_A: C28.1, R18.2; also elsewhere on the board
/SENSEH_A: R20.2; also elsewhere on the board
/SENSELF_A: C22.1, R12.2; also elsewhere on the board
/SENSEL_A: R14.2; also elsewhere on the board
/VIOUTN_A: CR4.2; also elsewhere on the board
/VIOUTP_A: Q3.4 (S); also elsewhere on the board
GNDA: C22.2, C25.2, C28.2, D4.2; also elsewhere on the board
unnamed: CR4.1, Q3.1 (D), Q3.2 (D), Q3.5 (D), Q3.6 (D)
unnamed: CR4.3, R15.1, R18.1, R20.1

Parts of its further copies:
C6, C7, C8, C9, C12, C13, C21, C26, C27: 10 nF; C_0402_1005Metric; Voltage Rating DC 100 VDC; Tolerance 10%; MPN C1005X7S2A103K050BB
C10, C11, C23: 220 pF; C_0402_1005Metric; Voltage Rating DC 100 VDC; Tolerance 5%; MPN CGA2B2NP02A221J050BA
CR1, CR2, CR3: 100 V; SC_70; MPN SBAV99WT1G
D1, D2, D3: 40 V; DO-214AB-2; MPN SMCJ40A/CA
Q1, Q2, Q4: -60 V; SOT-26; MPN ZXMP6A17E6TA
R1, R2, R19: 2 kΩ; R_0402_1005Metric; Voltage Rating 50V; Tolerance 0.1%; MPN ERA-2AEB202X
R3, R4, R9, R10, R11, R17: 10 kΩ; R_0402_1005Metric; Voltage Rating 50V; Tolerance 1%; MPN ERJ-2RKF1002X
R5, R6, R16: 100 Ω; R_0805_2012Metric; Voltage Rating 150V; Tolerance 0.1%; MPN RT0805BRB07100RL
R7, R8, R13: 2 kΩ; R_0402_1005Metric; Voltage Rating 50V; Tolerance 1%; MPN ERJ-2RKF2001X

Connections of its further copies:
/CASCODE_B: Q1.3 (G); also elsewhere on the board
/CASCODE_C: Q2.3 (G); also elsewhere on the board
/CASCODE_D: Q4.3 (G); also elsewhere on the board
/CCOMP_B: C11.2; also elsewhere on the board
/CCOMP_C: C10.2; also elsewhere on the board
/CCOMP_D: C23.2; also elsewhere on the board
/CHANNEL_2: C9.1, C11.1, D2.1, R6.2, R8.1, R10.1; also elsewhere on the board
/CHANNEL_3: C8.1, C10.1, D1.1, R5.2, R7.1, R9.1; also elsewhere on the board
/CHANNEL_4: C23.1, C26.1, D3.1, R11.1, R13.1, R16.2; also elsewhere on the board
/SENSEHF_B: C7.1, R4.2; also elsewhere on the board
/SENSEHF_C: C6.1, R3.2; also elsewhere on the board
/SENSEHF_D: C27.1, R17.2; also elsewhere on the board
/SENSEH_B: R2.2; also elsewhere on the board
/SENSEH_C: R1.2; also elsewhere on the board
/SENSEH_D: R19.2; also elsewhere on the board
/SENSELF_B: C13.1, R10.2; also elsewhere on the board
/SENSELF_C: C12.1, R9.2; also elsewhere on the board
/SENSELF_D: C21.1, R11.2; also elsewhere on the board
/SENSEL_B: R8.2; also elsewhere on the board
/SENSEL_C: R7.2; also elsewhere on the board
/SENSEL_D: R13.2; also elsewhere on the board
/VIOUTN_B: CR2.2; also elsewhere on the board
/VIOUTN_C: CR1.2; also elsewhere on the board
/VIOUTN_D: CR3.2; also elsewhere on the board
/VIOUTP_B: Q1.4 (S); also elsewhere on the board
/VIOUTP_C: Q2.4 (S); also elsewhere on the board
/VIOUTP_D: Q4.4 (S); also elsewhere on the board
GNDA: C6.2, C7.2, C8.2, C9.2, C12.2, C13.2, C21.2, C26.2, C27.2, D1.2, D2.2, D3.2; also elsewhere on the board
unnamed: CR1.1, Q2.1 (D), Q2.2 (D), Q2.5 (D), Q2.6 (D)
unnamed: CR1.3, R1.1, R3.1, R5.1
unnamed: CR2.1, Q1.1 (D), Q1.2 (D), Q1.5 (D), Q1.6 (D)
unnamed: CR2.3, R2.1, R4.1, R6.1
unnamed: CR3.1, Q4.1 (D), Q4.2 (D), Q4.5 (D), Q4.6 (D)
unnamed: CR3.3, R16.1, R17.1, R19.1

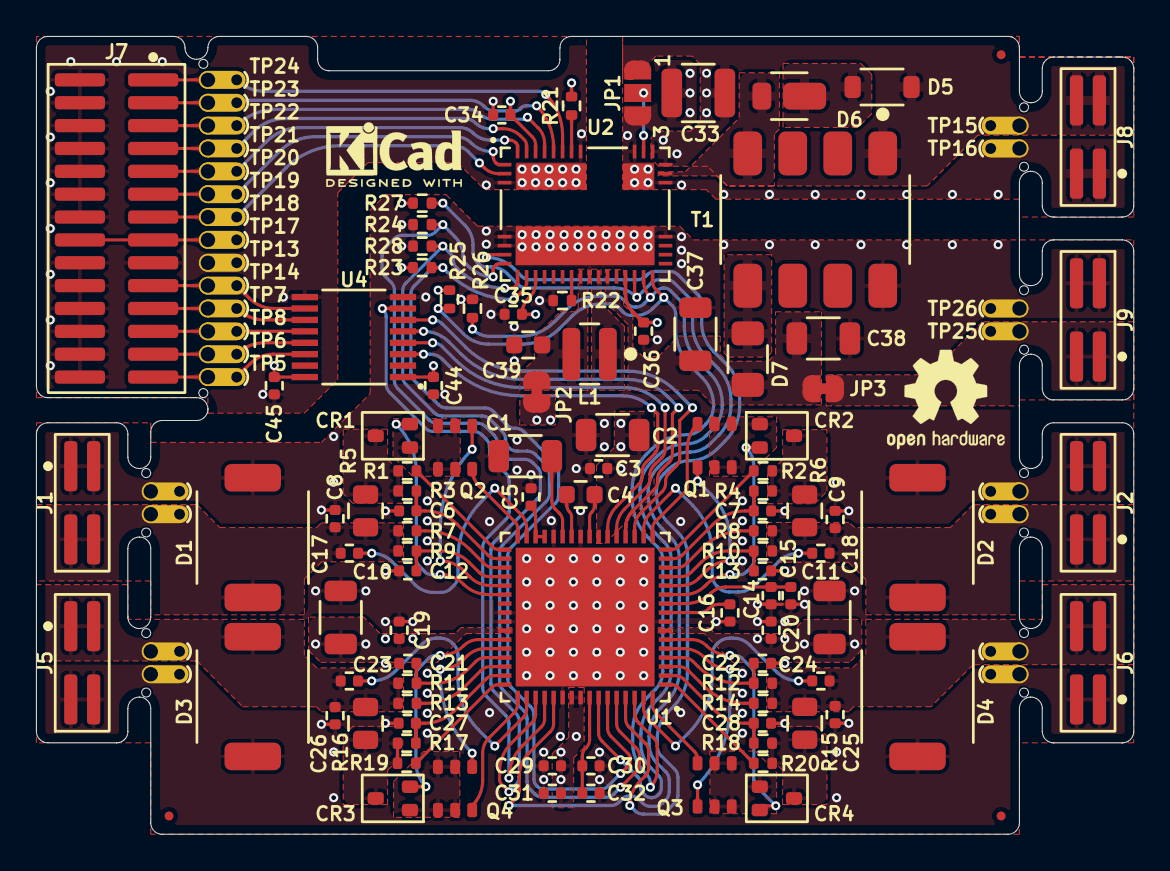
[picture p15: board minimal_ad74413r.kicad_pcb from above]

Board: 4 copper layers, 61.0 x 44.3 mm, 135 parts (0 on the bottom side), 91 nets.

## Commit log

2025-01-22 Add the initial Kicad project
    [minimal_ad74413r.kicad_pcb, minimal_ad74413r.kicad_sch]
2025-01-22 Add KiCAD_Symbol_Generator as submodule
2025-01-26 Minor updates
    [Front End Channel 1.kicad_sch, minimal_ad74413r.kicad_pcb, minimal_ad74413r.kicad_sch]
2025-01-28 Update references in schematic and update subproject commit
    [Front End Channel 1.kicad_sch, minimal_ad74413r.kicad_pcb, minimal_ad74413r.kicad_sch]
2025-01-30 Minor updates to project files
    [minimal_ad74413r.kicad_pcb, minimal_ad74413r.kicad_sch]
2025-01-30 Update subproject commit and add mouse bite footprints to fp-lib-table
    [minimal_ad74413r.kicad_pcb]
2025-01-31 Update subproject commit in KiCAD_Symbol_Generator
    [minimal_ad74413r.kicad_pcb]
2025-02-03 Update project files and improve organization
    [minimal_ad74413r.kicad_pcb]
2025-02-07 Update subproject commit and add new configuration and library entries for KiCAD_Symbol_Generator
    [minimal_ad74413r.kicad_pcb, minimal_ad74413r.kicad_sch]
2025-03-01 Update subproject commit and add new library entries for KiCAD_Symbol_Generator
    [minimal_ad74413r.kicad_pcb, minimal_ad74413r.kicad_sch]
2025-03-02 Update project files and enhance structure
    [minimal_ad74413r.kicad_pcb, minimal_ad74413r.kicad_sch]
2025-03-02 Update reference properties in minimal_ad74413r schematic
    [minimal_ad74413r.kicad_pcb, minimal_ad74413r.kicad_sch]
2025-03-10 Update subproject commit for KiCAD_Symbol_Generator
    [Front End Channel 1.kicad_sch, minimal_ad74413r.kicad_pcb, minimal_ad74413r.kicad_sch]
2025-03-16 Remove KiCAD_Symbol_Generator submodule reference
2025-03-16 Add KiCAD_Symbols_Generator submodule for minimal_ad74413r
2025-03-16 Update footprint library URIs to use KiCAD_Symbols_Generator
    [minimal_ad74413r.kicad_pcb]
2025-03-18 Switch to KiCad 9
    [Front End Channel 1.kicad_sch, minimal_ad74413r.kicad_pcb, minimal_ad74413r.kicad_sch]
2025-03-20 Update subproject commit reference for KiCAD Symbols Generator
2025-03-20 Add top image and update dimensions in KiCAD project for minimal_ad74413r
    [minimal_ad74413r.kicad_pcb]
2025-03-22 Update README.md to include project dependencies and setup instructions for KiCAD and 3D models
2025-04-05 Development backup
    [minimal_ad74413r.kicad_pcb]
2025-04-06 Add schematic export job and output folder for minimal_ad74413r
2025-04-06 Add schematic PDF for minimal_ad74413r
2025-04-07 Update subproject commit for KiCAD Symbols Generator
2025-04-07 Update schematic PDF for minimal_ad74413r with new components and layout adjustments
2025-04-08 Update schematic PDF for minimal_ad74413r with layout enhancements and component adjustments
2025-04-11 Update schematic PDF for minimal_ad74413r
2025-04-14 update minimal_ad74413r footprint
    [minimal_ad74413r.kicad_pcb, minimal_ad74413r.kicad_sch]
2025-04-18 Update KiCad documentation (schematics and PCB renders)
2025-04-19 Add Gruvbox theme support for KiCad PDF export
2025-04-23 Remove unused rendering jobs from project_jobs_set.kicad_jobset
2025-04-23 Refactor KiCad configuration handling and update documentation generation workflow
2025-04-23 Update KiCad documentation for minimal_ad74413r (schematics and PCB renders)
2025-04-23 Update KiCad configuration for improved rendering quality and adjust zoom/pan settings
2025-04-24 Enhance KiCad job generation workflow with improved configuration extraction and 3D model handling
2025-05-23 Add GitHub Actions workflow to generate KiCad 3D models
2025-05-25 Update trigger branch for KiCad 3D models generation workflow
2025-08-18 Add bottom view rendering to KiCad workflow and update configuration
2025-08-22 Update KiCad workflow configurations
2025-08-28 Update KiCad workflows to use newer Docker image and add Interactive HTML BOM generation
2025-10-05 chore: update workflows and kicad config from central repository
2025-10-26 Update kicad-config workflow settings
